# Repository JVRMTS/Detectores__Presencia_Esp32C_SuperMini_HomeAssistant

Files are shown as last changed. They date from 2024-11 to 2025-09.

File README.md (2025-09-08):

<h1>DETECTORES DE PRESENCIA UTILIZANDO ESP32C3 SUPER MINI Y LD2410 Y LD2420 PARA ESPHOME Y HOMEASSISTANT</h1>
<P>Despues de estar buscando como configurar los detectores de presencia HLK-LD2410 y HLK-LD2420 y ver que habia poca información,
  me dedique a realizar pruebas para intentar configurarlos, de esas pruebas llegan estos resultados:</P>

<p>He conseguido configurar los dos, y si te fijas en los archivos YAML verás que hay que cambiar los pines 20 y 21 dependiendo 
del sensor que estés utilizando, no se si es por una mala definición de los pines en las placas que tengo o porque estan mal serigrafiados, 
el caso es que así funcionan los dos.</p>

<p>También he realizado dos bocetos en Fritzing para ponerlos en funcionamiento, tiene la PCB diseñada, actualmente los tengo los dos funcionando.</p>

<P>Los dos tienen una fuente de alimentación HLK-PM01 de 5V y 0.6A se alimentan a 220V de corriente alterna, pues tengo intención de colocarlos 
pegados a los plafones que tengo y sacar la alimentación desde estos.</P>
<h2>NOTA 22/07/2025</h2>
<p>El LD2420 me ha fallado al actualiarlo con la versión 2025.7.2 de ESPHOME, funciona con la versión 2025.6.3</p>
<h2>NOTA 06/09/2025</h2>
<p>Desde la actualización 2025.7.2 de ESPHOME dejó de funcionar si se actualizaba por encima de esa versión de ESPHOME, para que funcione hay que con las versiones iguales o superiores a esa hay que cambiar los pines a los que se conecta el HLK-LD2024 - tx_pin: GPIO07 y rx_pin: GPIO06, con la configuración antigua daba problemas con el puerto USB.</p>
<h2>NOTA 08/09/2025</h2>
<p>Despues de hacer varias pruebas me he dado cuenta de que, aparte de cambiar los pines, tambien hay que cortar la corriente al circuito para que funcione, pues cuando se reinicia tras la actualización da error y cuando se le corta la corriente funciona correctamente.</p>

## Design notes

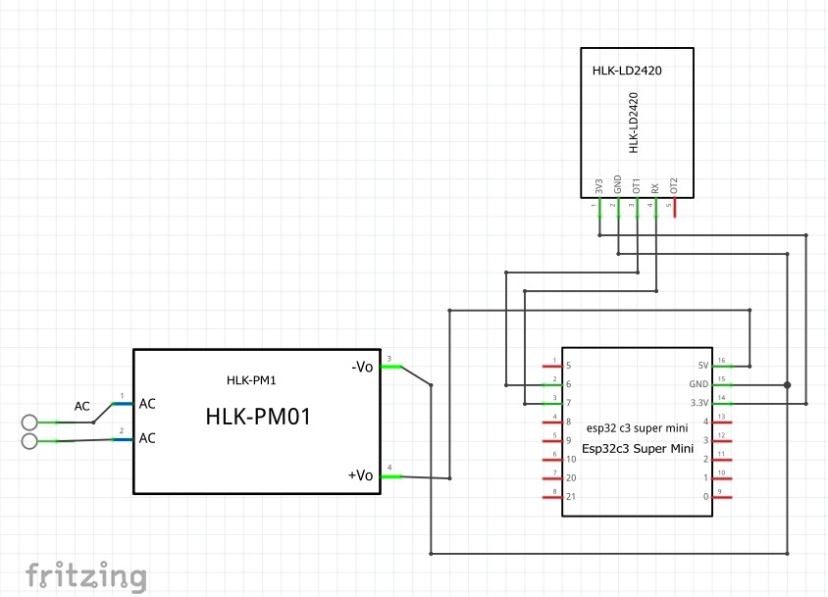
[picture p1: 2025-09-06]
HLK-LD2420/ESP32C3SM_LD2420_esquemático.jpg

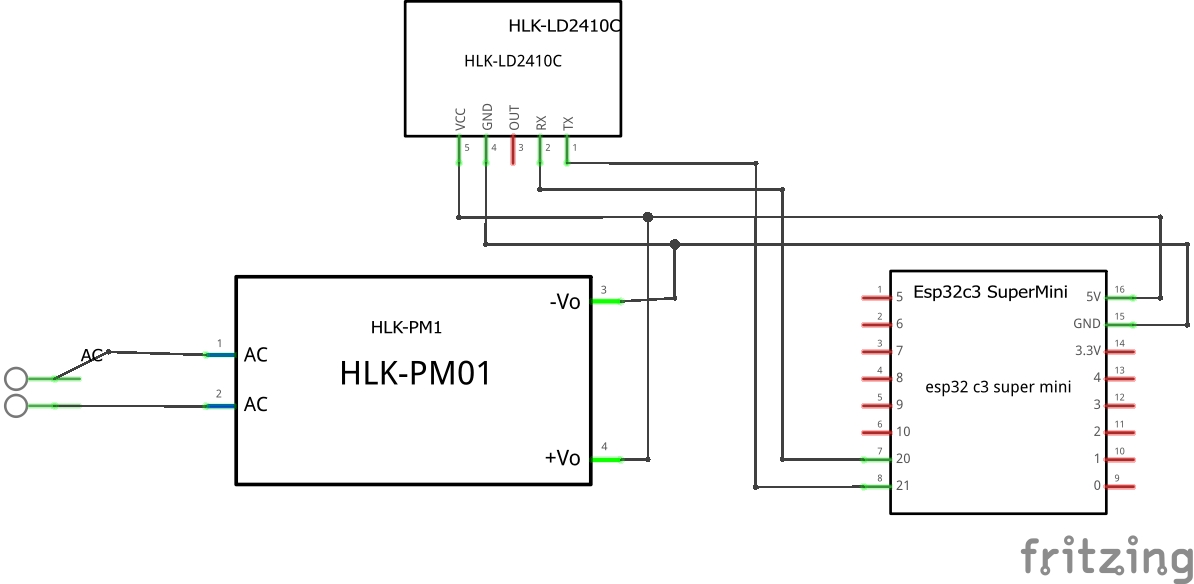
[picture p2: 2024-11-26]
HLK-LD2410/ESP32C3SM_LD2410_esquemático.jpg

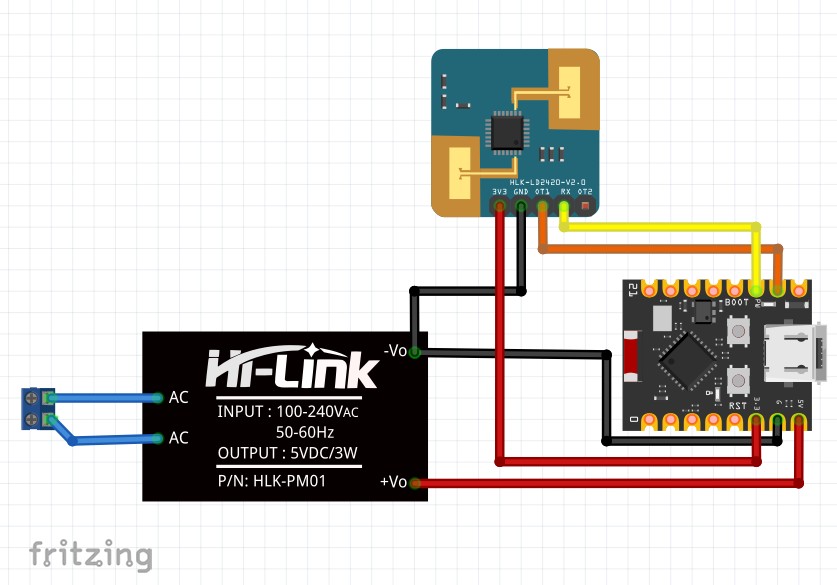
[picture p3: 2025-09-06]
HLK-LD2420/ESP32C3SM_LD2420_bb.jpg

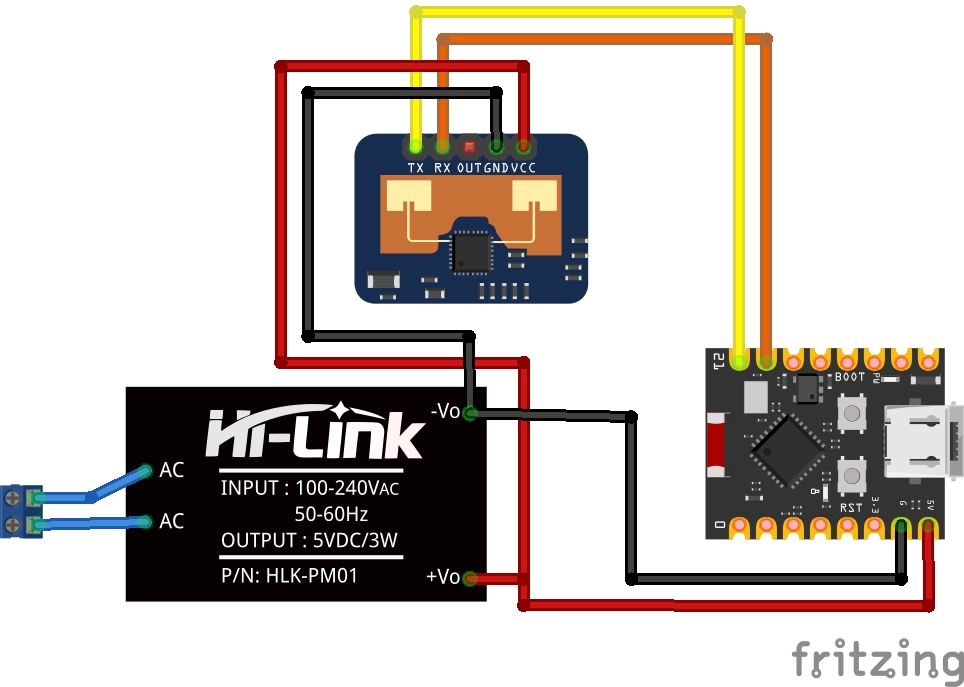
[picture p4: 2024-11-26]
HLK-LD2410/ESP32C3SM_LD2410_bb.jpg

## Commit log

2025-07-22 Update README.md
    Fallo de funcionamiento con la versión 2025.7.2 de ESPHOME
2025-07-22 Binarios para LD2420 con ESPHOME 2025.6.3
    Binarios para LD2420 con ESPHOME 2025.6.3
2025-09-06 Update PRESENCIA_HLK-LD2420_ESP32CSM.yaml
    Cambio de pines de UART
2025-09-06 Cambio de imágenes y archivo frtitzing
    [ESP32C3SM_LD2420.fzz]
